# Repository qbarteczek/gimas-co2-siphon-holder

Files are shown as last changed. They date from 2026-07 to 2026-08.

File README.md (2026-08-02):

# 🍾 GIMAS Soda Siphon CO2 Cartridge Holder (8g & 12g)



[]()

Cześć! Wrzucam tutaj projekt fajnych, zgrabnych uchwytów (nakładek) na naboje CO2 (te małe 8g i te większe 12g) do klasycznych syfonów **GIMAS**. 

Pliki STL to jedna, spójna bryła (watertight) z wbudowanym gwintem **M20.7 x 2.0**, który pasuje prosto do metalowej szyjki syfonu. Od góry jest zaokrąglona czapeczka, żeby nabój ładnie siedział i dociskał iglicę.

---

## 🎨 4 Wyglądy do wyboru

Mamy tu 4 opcje stylistyczne, każda dla wersji 8g i 12g:

| # | Jak wygląda | Nazwa | O co chodzi? | Plik STL (8g) | Plik STL (12g) |
|---|:---:|---|---|---|---|
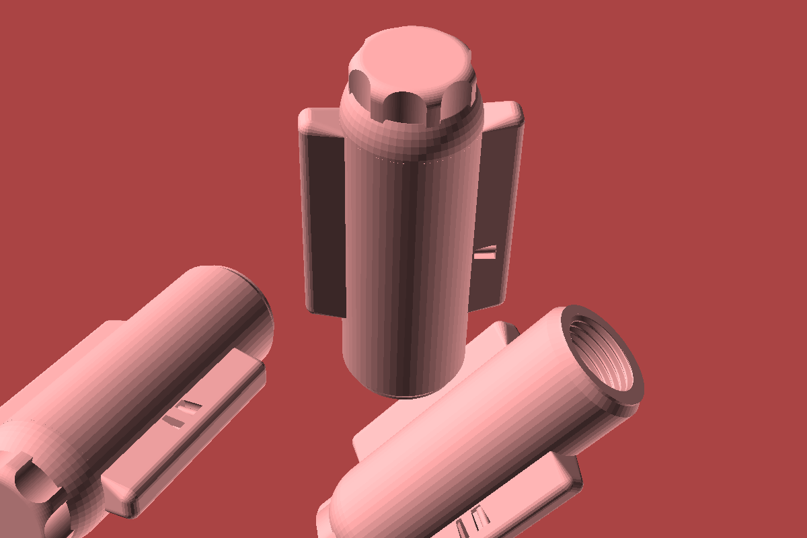
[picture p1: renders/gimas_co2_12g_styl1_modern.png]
| **1** |  | **Modern Minimalist** | Gładziutki z dwoma łopatkami, dobrze leży w łapie, łatwo umyć | [`8g Modern`](stl/gimas_co2_8g_styl1_modern.stl) | [`12g Modern`](stl/gimas_co2_12g_styl1_modern.stl) |
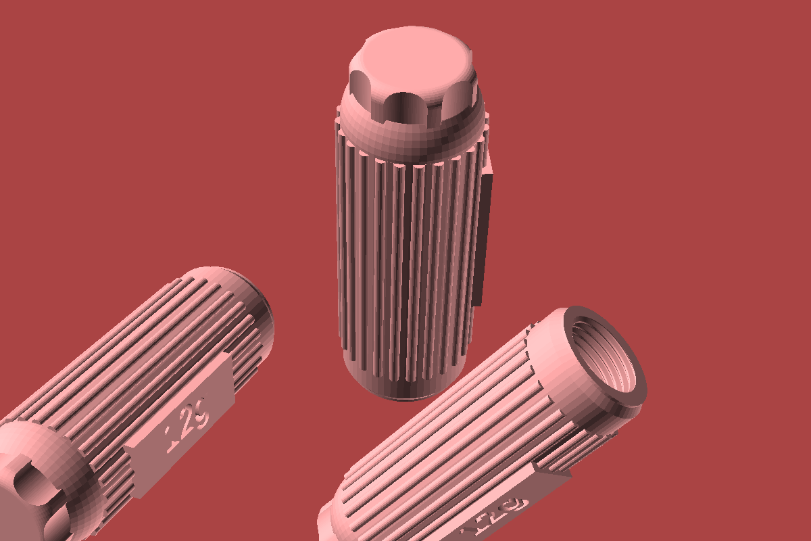
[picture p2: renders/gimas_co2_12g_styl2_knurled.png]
| **2** |  | **Industrial Knurled** | Nacięte paski wzdłuż, super chwyt, nawet jak masz mokre ręce | [`8g Knurled`](stl/gimas_co2_8g_styl2_knurled.stl) | [`12g Knurled`](stl/gimas_co2_12g_styl2_knurled.stl) |
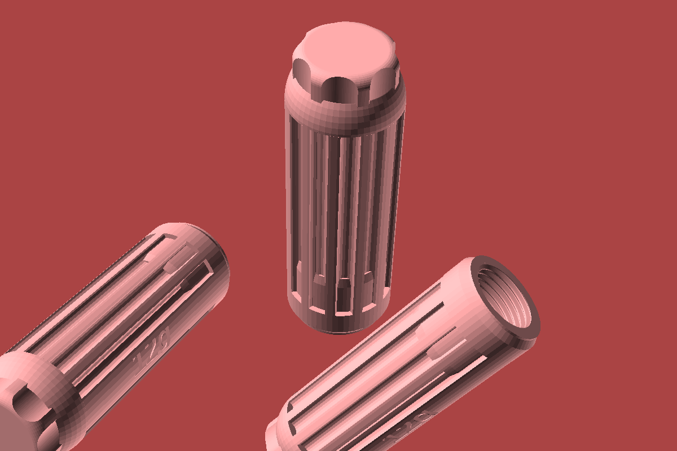
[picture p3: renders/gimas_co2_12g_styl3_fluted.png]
| **3** |  | **Retro Fluted** | Klasyczne, głębsze rowki. Wygląda jak stare syfony z lat 70. | [`8g Fluted`](stl/gimas_co2_8g_styl3_fluted.stl) | [`12g Fluted`](stl/gimas_co2_12g_styl3_fluted.stl) |
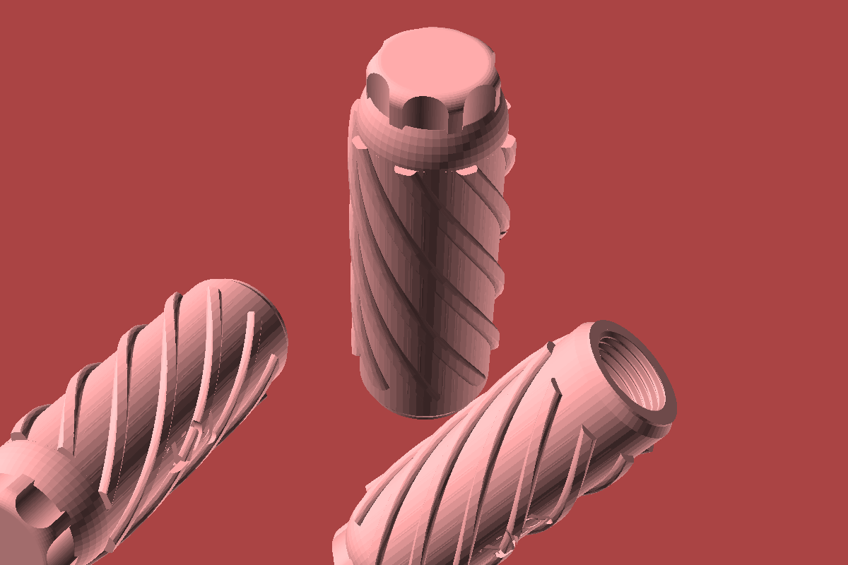
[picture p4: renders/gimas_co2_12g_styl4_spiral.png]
| **4** |  | **Ergonomic Spiral** | Zakręcony świderek, wygodnie się dokręca | [`8g Spiral`](stl/gimas_co2_8g_styl4_spiral.stl) | [`12g Spiral`](stl/gimas_co2_12g_styl4_spiral.stl) |

---

## 📚 Gdzie szukać pomocy?

W folderze [`docs/`](docs/) wrzuciłem kilka poradników:

1. 🖨️ **[Poradnik Druku 3D](docs/TUTORIAL_3D_PRINTING.md)**
   - Jak to pociąć w slicerze (Prusa, Bambu, Cura).
   - Z czego drukować (spoiler: PETG wymiata), żeby gwint nie strzelił.
   - Jak ustawić to na stole (podpowiem: bez podpór!).

2. 🛠️ **[Poradnik Modyfikacji w OpenSCAD](docs/TUTORIAL_OPENSCAD_CUSTOMIZATION.md)**
   - Jak bawić się suwakami w `scad/gimas_co2_holder.scad`.
   - Jak dodać własny tekst na boku.
   - Jak odpalić skrypty, jak wolisz klepać w terminalu.

3. 🍾 **[Instrukcja do Syfonu GIMAS](docs/SIPHON_USAGE_GUIDE.md)**
   - Krótka ściąga, jak ładować gaz i nie zrobić w kuchni powodzi.

---

## 🖨️ Drukujemy (szybka ściąga)

> [!TIP]
> **Na szybko:**
> - **Pozycja:** Dnem do dołu (gwint na górze).
> - **Warstwa:** `0.16 mm` (dla ładnego gwintu) albo `0.20 mm`.
> - **Obrysy (Walls):** Dajcie co najmniej **4-5**, żeby gwint wytrzymał wkręcanie!
> - **Wypełnienie:** `25% - 30%` (Gyroid robi robotę).
> - **Podpory:** **Wyłącz**, szkoda plastiku, wydrukuje się ładnie bez tego.
> - **Filament:** **PETG** to król w tym przypadku, ewentualnie ASA/ABS.

---

## 🛠️ Zabawa z OpenSCADem

Plik [`scad/gimas_co2_holder.scad`](scad/gimas_co2_holder.scad) to czysty kod, możesz zmieniać co chcesz.

### Jak zrzucić model z konsoli:
```bash
# Szybki 8g Modern:
openscad -D 'size="8g"' -D 'style=1' -o stl/gimas_co2_8g_styl1_modern.stl scad/gimas_co2_holder.scad

# Albo 12g w prążki:
openscad -D 'size="12g"' -D 'style=2' -o stl/gimas_co2_12g_styl2_knurled.stl scad/gimas_co2_holder.scad
```

### Chcesz machnąć wszystko na raz?
Mamy skrypt w Pythonie:
```bash
python3 scripts/build_stl_and_renders.py
```

---

## 📐 Wymiary i technikalia

- **Gwint:** M20.7 x 2.0 (taki nietypowy, ale w syfonach siedzi idealnie).
- **Całkowita długość 8g:** 73.0 mm (szerokość to 30.0 mm).
- **Całkowita długość 12g:** 90.0 mm (szerokość ta sama).
- **Góra:** Zaokrąglona czapeczka, która bezpiecznie dopycha nabój do iglicy.

---

## 📜 Licencja

Bawcie się dobrze, projekt jest na licencji [MIT](LICENSE).

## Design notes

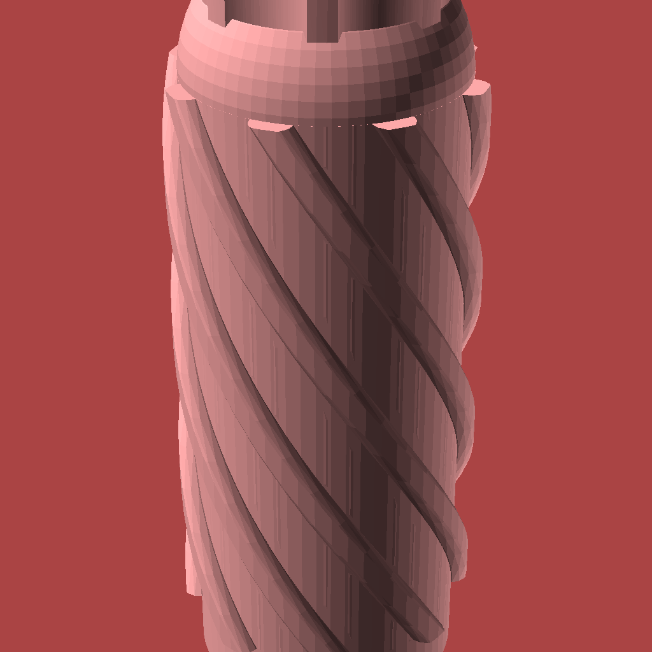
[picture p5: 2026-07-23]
renders/gimas_co2_8g_styl4_spiral.png

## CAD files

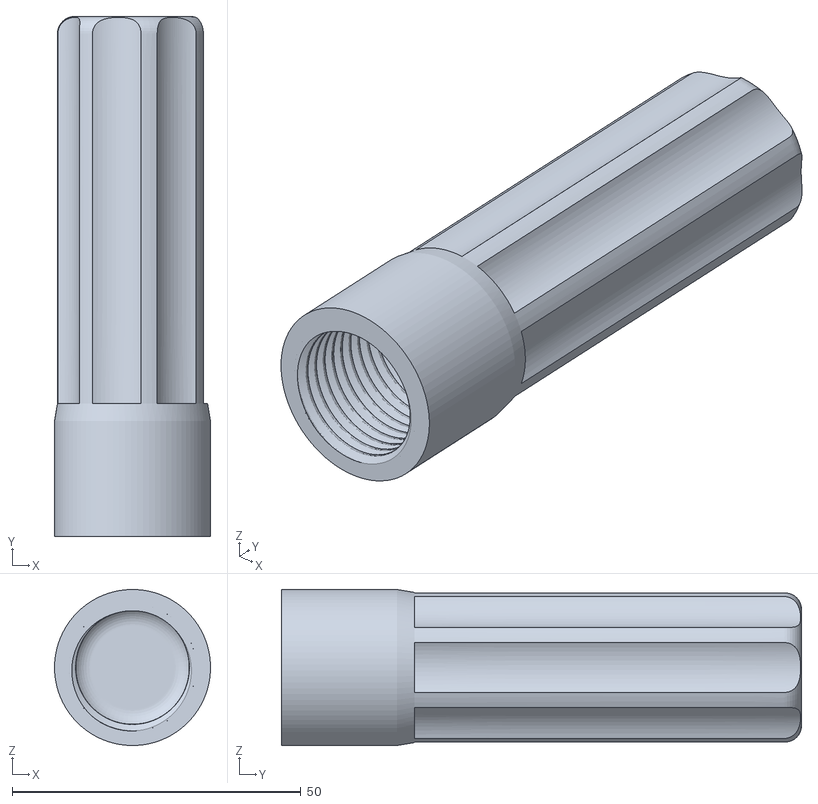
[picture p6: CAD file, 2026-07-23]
scad/base_12g.stl
27.0 x 90.0 x 27.0

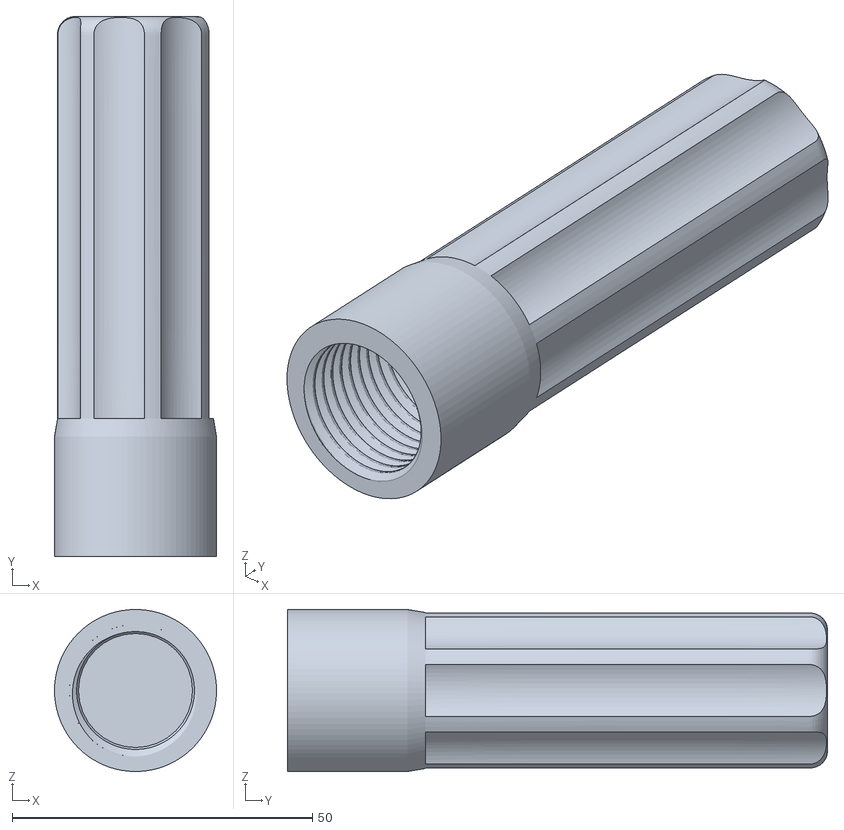
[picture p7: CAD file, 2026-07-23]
scad/base_8g.stl
27.0 x 90.0 x 27.0

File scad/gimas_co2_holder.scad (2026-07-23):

// ==============================================================================
// GIMAS Siphon CO2 Cartridge Holder Generator
// Parametric OpenSCAD design for 8g and 12g CO2 Seltzer Siphon Holders
// Genuine GIMAS M20.7 Female Thread & Solid Top Cap
// ==============================================================================

size = "12g"; // "8g" or "12g"
style = 1;     // 1: Modern Minimalist, 2: Knurled, 3: Fluted, 4: Spiral
$fn = 60;

// Dimensions calculation based on size
total_length = (size == "8g") ? 73 : 90;
label_text   = (size == "8g") ? "8g" : "12g";

// Helper module: main cylinder with smooth hemispherical dome top cap ("półokrągła czapeczka")
module base_body_with_dome(len) {
    union() {
        cylinder(r1=13, r2=15, h=3);
        translate([0, 0, 3]) cylinder(r=15, h=max(0, len - 3 - 15));
        translate([0, 0, len - 15]) sphere(r=15, $fn=60);
    }
}

// -------------------------------------------------------------
// STYL 1: Modern Minimalist (Opływowy z 2 łopatkami i półokrągłą czapeczką)
// -------------------------------------------------------------
module style_modern(len) {
    union() {
        base_body_with_dome(len);
        for (i=[0, 180]) {
            rotate([0, 0, i]) translate([13, 0, 0])
            hull() {
                translate([0, -4, 20]) cylinder(r=1, h=max(0, len-36));
                translate([0, 4, 20]) cylinder(r=1, h=max(0, len-36));
                translate([8, -1.5, 22]) sphere(r=2.5, $fn=24);
                translate([8, 1.5, 22]) sphere(r=2.5, $fn=24);
                translate([8, -1.5, len-16]) sphere(r=2.5, $fn=24);
                translate([8, 1.5, len-16]) sphere(r=2.5, $fn=24);
            }
        }
    }
}

// -------------------------------------------------------------
// STYL 2: Industrial Knurled (Radełkowany z półokrągłą czapeczką)
// -------------------------------------------------------------
module style_knurled(len) {
    union() {
        base_body_with_dome(len);
        for (a=[0:15:345]) {
            rotate([0, 0, a]) translate([14.8, 0, 10]) cylinder(r=1.2, h=len-25, $fn=20);
        }
        rotate([0, 0, 0]) translate([13.5, -7, len/2 - 20]) cube([3, 14, 40]);
    }
}

// -------------------------------------------------------------
// STYL 3: Retro Fluted (Klasyczne bruzdy z półokrągłą czapeczką)
// -------------------------------------------------------------
module style_fluted(len) {
    difference() {
        base_body_with_dome(len);
        for (a=[0:30:330]) {
            if (a != 0 && a != 180) {
                rotate([0, 0, a]) translate([15, 0, 10]) cylinder(r=2.5, h=len-25, $fn=20);
            }
        }
    }
}

// -------------------------------------------------------------
// STYL 4: Ergonomic Spiral (Futurystyczny świder z półokrągłą czapeczką)
// -------------------------------------------------------------
module style_spiral(len) {
    union() {
        base_body_with_dome(len);
        intersection() {
            cylinder(r=16.8, h=len);
            translate([0, 0, 10])
            linear_extrude(height=len-25, twist=160, $fn=36) {
                circle(r=15, $fn=36);
                for (a=[0:45:315]) {
                    rotate([0, 0, a]) translate([15, 0]) circle(r=2.2, $fn=16);
                }
            }
        }
    }
}

module sleeve_shell(len, stl_style, text_str) {
    difference() {
        if (stl_style == 1) style_modern(len);
        else if (stl_style == 2) style_knurled(len);
        else if (stl_style == 3) style_fluted(len);
        else if (stl_style == 4) style_spiral(len);
        else style_modern(len);
        
        // Hollow core to wrap genuine base
        translate([0, 0, -1]) cylinder(r=12.5, h=len+2);
        
        // Debossed vertical text
        rotate([0, 0, 0]) translate([14.6, 0, len/2]) rotate([90, 0, 90]) rotate([0, 0, -90])
        linear_extrude(height=5) text(text_str, size=8, font="Liberation Sans:style=Bold", halign="center", valign="center");
    }
}

// Master module combining genuine GIMAS siphon base (with M20.7 thread & solid top) and aesthetic sleeve
module gimas_co2_holder(total_len, stl_style, text_str) {
    union() {
        // Genuine GIMAS Siphon Base with M20.7 Female Thread & Internal Cavity
        if (size == "8g") {
            import("base_8g.stl");
        } else {
            import("base_12g.stl");
        }
        
        // Outer aesthetic sleeve aligned to base
        translate([0, 0, 13.5]) 
        rotate([-90, 0, 0]) 
        translate([0, 0, (size == "8g") ? -41.24 : -58.24]) 
        sleeve_shell(total_len, stl_style, text_str);
    }
}

gimas_co2_holder(total_length, style, label_text);

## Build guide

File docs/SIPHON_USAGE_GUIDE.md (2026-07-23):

# 🍾 Krótka instrukcja: jak zrobić bąbelki w syfonie GIMAS

Cześć! Skoro już wydrukowałeś sobie uchwyt, to pora przejść do przyjemniejszej części – robimy wodę gazowaną!
Syfony **GIMAS** to stare poczciwe sprzęty, ale trzeba pamiętać o paru podstawowych zasadach, żeby cała kuchnia nie latała w powietrzu.

---

## 🛑 Ważne sprawy (Bezpieczeństwo przede wszystkim)

1. **Używaj tylko nabojów spożywczych** (do wody, a nie do wiatrówek czy pompowania opon w rowerze!). Mają odpowiedni gaz i są czyste.
2. **Kategorycznie nie otwieraj syfonu**, kiedy jest nagazowany. Zawsze upuść resztkę ciśnienia nad szklanką, zanim cokolwiek odkręcisz.
3. **Naboje trzymaj w suchym chłodnym miejscu**. Zostawianie ich latem w aucie to słaby pomysł (przy +50°C może być różnie).

---

## 🛠️ Jedziemy z tematem – krok po kroku

### Krok 1: Woda, zimna i najlepiej z filtra
- Odkręcasz głowicę syfonu i wlewasz wodę. Pamiętaj: im zimniejsza woda, tym lepsze bąbelki wyjdą (CO2 lepiej rozpuszcza się w zimnym).
- **Nie dolewaj do pełna!** Wewnątrz musi zostać trochę pustego miejsca dla rozprężającego się gazu, zwykle jest tam specjalna rurka miarkująca.
- Nakręć główną głowicę mocno z powrotem.

### Krok 2: Czas na nabój
- Bierzemy nowiutki nabój CO2 (8g lub 12g – zależy jaki wydrukowałeś uchwyt).
- Wrzucasz go do plastikowego uchwytu szyjką (węższą stroną) do góry, tam gdzie widać gwint.

### Krok 3: Pssst! (Wkręcamy uchwyt)
- Przyłóż uchwyt do gwintu na syfonie.
- Wkręcaj prosto (zgodnie ze wskazówkami zegara). Nie używaj siły z samego początku – gwint ma wchodzić leciutko.
- W pewnym momencie poczujesz mocny opór, bo iglica dotknęła zaślepki naboju. Wtedy **szybkim, dość mocnym ruchem kręcisz dalej**.
- Usłyszysz głośne "pssssst" – gaz właśnie poleciał do wody. Kręć do oporu, aż syk ucichnie.

### Krok 4: Shake it!
- Syfon lubi, jak się nim trochę pobuja. Złap go mocno i potrzęś z 10-15 razy. Woda musi ładnie wymieszać się z gazem.
- Postaw to na 1-2 minuty, daj odpocząć bąbelkom.

### Krok 5: Pijemy na zdrowie
- Naciskasz wihajster (dźwignię) i woda leci do szklanki!
- Kiedy woda wyjdzie z gazem całkowicie do dna i nic w syfonie już nie ma ciśnienia, możesz odkręcić plastikowy uchwyt i wyrzucić pusty metalowy nabój na złom/do żółtego kosza.

---

## 📏 8g czy 12g? Krótka różnica

- **Nabój 8g (Klasyk):** Zazwyczaj wystarcza na 1 litr wody. Zrobi z tego przyjemną, lekką wodę gazowaną.
- **Nabój 12g (Dla fanów mocnego kopa):** Pakujesz więcej gazu – bąble będą szczypać w język znacznie mocniej, albo używasz go jak masz większy syfon.
- Ważne: nakładki drukujemy pod konkretny nabój! Wersja `8g` ma krótszą lufę, żeby docisnąć mały nabój, a `12g` jest odpowiednio wyższa. Nie mieszaj ich.

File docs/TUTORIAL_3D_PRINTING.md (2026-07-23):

# 🖨️ Jak to wydrukować? (Poradnik Druku 3D)

Krótka piłka: ten uchwyt musi wytrzymać trochę siły, jak dokręcasz gaz do syfonu **GIMAS**. Dlatego gwint M20.7 to najważniejszy punkt zabawy. Niżej zebrałem ustawienia, które sprawdzą się u każdego.

---

## 📐 Slicer – o czym pamiętać

| Ustawienie | Co dać | Po co to? |
|:---|:---|:---|
| **Jak położyć na stole** | **Dnem na blachę** (gwint do góry) | Żeby łatwo schłodzić gwint i uniknąć nawisów, które mogłyby wszystko zepsuć. |
| **Wysokość warstwy** | `0.16 mm` lub `0.20 mm` | Przy `0.16 mm` gwint wyjdzie po prostu masełko. |
| **Obrysy (Walls)** | **4 do 5 sztuk** | **Najważniejsze!** Nie żałuj obrysów. Gwint musi być twardy jak skała, a z małą ilością ścianek wypełnienie tylko osłabi sprawę. |
| **Góra/Dół (Top/Bottom)** | **5 warstw z góry i dołu** | Czapeczka na górze musi znieść ciśnienie dociskanego naboju. |
| **Wypełnienie** | `25% - 30%` | Daj Gyroid (żyroid) – fajnie znosi siły z każdej strony. |
| **Podpory (Supports)** | **Wyłącz (Off)** | Szkoda czasu, model tak zaprojektowałem, że puści bez żadnych rusztowań. |

---

## 🧵 Z czego drukujemy?

1. **PETG (Zdecydowanie polecam):**
   - **Plusy:** Plastik, który wybacza dużo, ładnie się klei i nie pęknie ci gwint, jak będziesz go mocno dokręcać co weekend.
   - **Temperatury:** Zależy od szpuli, ale celuj w `230-240°C` i stół na `70-80°C`.

2. **ASA / ABS:**
   - **Plusy:** Pancerne, do tego jak ktoś lubi, to wygładzi oparami z acetonu i wyjdzie "jak z fabryki".
   - **Minusy:** Musisz uważać na skurcz. Jak ci podwinie, gwint nie wejdzie. Lepiej drukować w komorze.

3. **PLA (Jak nie masz nic innego):**
   - **Plusy:** Drukuje się samo, jest bardzo twarde.
   - **Minusy:** Daj to pod gorącą wodę i popłynie. Żadnych zmywarek! 

---

## 💡 Składanie i drobne patenty

1. **Pierwsze podejście z gwintem:**
   - Wiadomo, plastikowy gwint potrzebuje chwili, żeby dogadać się z metalem w syfonie. Wkręcaj z czuciem, jeśli idzie ciężko, wkręć trochę i wykręć – taki "tapping" na szybko.
2. **Dodaj trochę poślizgu:**
   - Możesz kropnąć odrobinę smaru silikonowego (spożywczego) na gwint. Później wkręca się jednym palcem.
3. **Zapinamy pasy:**
   - Jak wrzucisz nabój i zakręcasz uchwyt, zrób to płynnym, zdecydowanym ruchem na samym końcu. Usłyszysz syk, dociśnij do końca i gotowe!

---

## ❓ FAQ – co może pójść nie tak?

- **Q: Kurde, gwint wchodzi megaciężko, co robić?**
  - *A:* Odpal w slicerze opcję `Slicing Tolerance` i rzuć na `Exclusive` (lub zmień `XY Size Compensation` o np. `-0.05 mm`). Trochę to zluzuje szczeliny.
- **Q: Góra mi nie pęknie jak docisnę nabój?**
  - *A:* Spokojna głowa! Dałem tam ze 4 milimetry pełnego plastiku. Przy 5 obrysach można po tym niemalże skakać, iglicę przebije na luzie.

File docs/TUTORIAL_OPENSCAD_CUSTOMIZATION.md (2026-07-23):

# 🛠️ Bawimy się w OpenSCAD (Parametryzacja)

W folderze siedzi sobie plik `scad/gimas_co2_holder.scad` – to całe serce projektu. Jeśli chcesz wyczarować coś swojego na stary poczciwy syfon **GIMAS**, to dobrze trafiłeś. Kod jest podzielony tak, że bardzo łatwo cokolwiek zmienić.

---

## 🚀 Czego potrzebujesz?

- **OpenSCAD** w miarę świeży (od 2021.01). Darmowy, pobierzesz z [openscad.org](https://openscad.org/).
- Opcjonalnie: Python 3 z `trimesh` i `pymeshlab`, jeśli chcesz zautomatyzować generowanie pięknych, czystych siatek (watertight). 

---

## ⚙️ Co możemy pozmieniać w kodzie?

Na samej górze pliku `scad/gimas_co2_holder.scad` masz kilka parametrów. Wygląda to tak:

```openscad
size = "12g"; // Zmieniasz na "8g" jak wolisz mniejsze naboje
style = 1;     // Tu wybierasz swój ulubiony wzorek
$fn = 60;      // Rozdzielczość siatki (60 to już ładne koło)
```

### 1. Duży czy mały gaz? (`size`):
- `size = "8g"` – Klasyk, idealny pod małe naboje. Ma 73 mm.
- `size = "12g"` – Większa pojemność, 90 mm długości.

### 2. Wybieramy styl (`style`):
- `style = 1` – **Modern Minimalist**: Schludny, z dwoma płetwami ułatwiającymi wkręcanie.
- `style = 2` – **Industrial Knurled**: Radełko po całości. Fajna sprawa jak masz mokre ręce.
- `style = 3` – **Retro Fluted**: Takie klasyczne, szerokie rowki w stylu retro.
- `style = 4` – **Ergonomic Spiral**: Świderek. Wygląda cool i dobrze prowadzi dłoń przy kręceniu.

---

## 💻 Klepanie w konsoli

Jak nie lubisz wyklikiwać z interfejsu, to odpalasz to ładnie z terminala:

```bash
# Dla fana małych nabojów, wersja gładka (Modern):
openscad -D 'size="8g"' -D 'style=1' -o stl/gimas_co2_8g_styl1_modern.stl scad/gimas_co2_holder.scad

# Albo 12g świderek:
openscad -D 'size="12g"' -D 'style=4' -o stl/gimas_co2_12g_styl4_spiral.stl scad/gimas_co2_holder.scad
```

---

## 🎨 Własne napisy? Czemu nie!

Jeśli zajrzysz do modułu `sleeve_shell()`, znajdziesz tam kawałek kodu robiący wklęsły napis na boku:

```openscad
// Tu dzieje się magia wytłaczania tekstu
rotate([0, 0, 0]) translate([14.6, 0, len/2]) rotate([90, 0, 90]) rotate([0, 0, -90])
linear_extrude(height=5) text(text_str, size=8, font="Liberation Sans:style=Bold", halign="center", valign="center");
```

Możesz tu wpisać własne imię, nazwę babci, ksywkę, albo zmienić czcionkę. Eksperymentuj!

---

## 🔄 Wszystko na jednym kliknięciu (Python)

Nie chcesz się bawić z jednym plikiem? Wrzuciłem skrypt, który robi wszystko za Ciebie. Złoży, zszyje, zrenderuje:

```bash
python3 scripts/build_stl_and_renders.py
```

Co dokładnie robi ten skrypt?
1. Przelatuje przez wszystkie 4 style i 2 rozmiary.
2. Odpala MeshLaba w tle, żeby idealnie scalić nasz ładny korpus z gwintem M20.7, tworząc wzorowego STL-a bez błędów.
3. Stawia to równiutko w pionie (Z=0).
4. Strzela całkiem przyjemne podglądy PNG (z 3 stron!).

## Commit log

2026-07-23 Initial commit: GIMAS CO2 Siphon Holder parametric OpenSCAD design and generation pipeline
    [gimas_co2_holder.scad]
2026-07-23 Fix top cap to be solid closed, refine M20.7 female thread, remove hexagonal style
    [gimas_co2_12g_styl5_spiral.stl, gimas_co2_holder.scad]
2026-07-23 Organizacja repozytorium, dodanie poradników (druk 3D, OpenSCAD, obsługa syfonu) oraz trójwidokowych podglądów PNG
    [base_12g.stl, base_8g.stl, gimas_co2_12g_styl5_spiral.stl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]

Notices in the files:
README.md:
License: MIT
